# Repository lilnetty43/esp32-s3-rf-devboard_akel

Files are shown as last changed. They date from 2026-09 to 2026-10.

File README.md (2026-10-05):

# ESP32-S3 4-Layer RF Development Board

This project is a custom 4-layer development board built around the ESP32-S3. I designed the board to expand my PCB design experience into an RF-aware layout, multi-layer stackup design, controlled-impedance USB routing, and manufacturing preparation.

My board include native USB-C programming and power, 5 V-to-3.3 V regulation, GPIO breakout headers, BOOT and RESET controls, protection circuitry, test points, and a programmable RGB status LED.

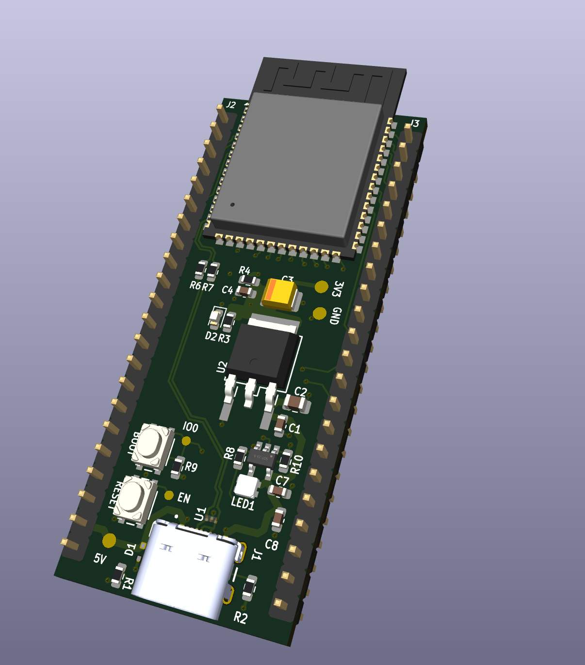
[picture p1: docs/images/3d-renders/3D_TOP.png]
3D Top View


*KiCad-generated 3D render of the ESP32-S3 development board.*

---

## Project Overview

The ESP32-S3 module provides Wi-Fi and Bluetooth connectivity using its integrated PCB antenna. The board exposes the ESP32-S3 GPIO through two headers while providing the supporting power, USB, programming, reset, and protection circuitry needed for standalone development.

A 4-layer PCB stackup was used to provide dedicated ground and power planes while maintaining short return paths and supporting controlled-impedance routing for the native USB interface.

---

## Details

- **MCU:** ESP32-S3 [LINK]
- **PCB:** 4-layer, 1.6 mm
- **USB:** USB-C with native ESP32-S3 USB programming[LINK]
- **USB Routing:** 90 Ω differential impedance target for D+/D−
- **Power Input:** 5V USB
- **Regulation:** 5V to 3.3V using LD1117S33 [LINK]
- **GPIO:** Dual breakout headers
- **Controls:** BOOT/RESET pushbuttons [LINK]
- **Protection:** USB ESD protection [LINK]
- **Status:** Programmable RGB LED [LINK]
- **Debugging:** Dedicated test points for important power and signal nets for debugging/checking

---

## PCB Stackup

The board uses a 4-layer stackup:
- **L1/F.Cu:** Components and signals
- **L2/In1.Cu:** Solid GND
- **L3/In2.Cu:** 3.3 V power 
- **L4/B.Cu:** Secondary signal routing

The stackup was configured around the intended JLCPCB manufacturing process rather than using KiCad's default layer construction.

---

## PCB Design Highlights [FIX!!!]

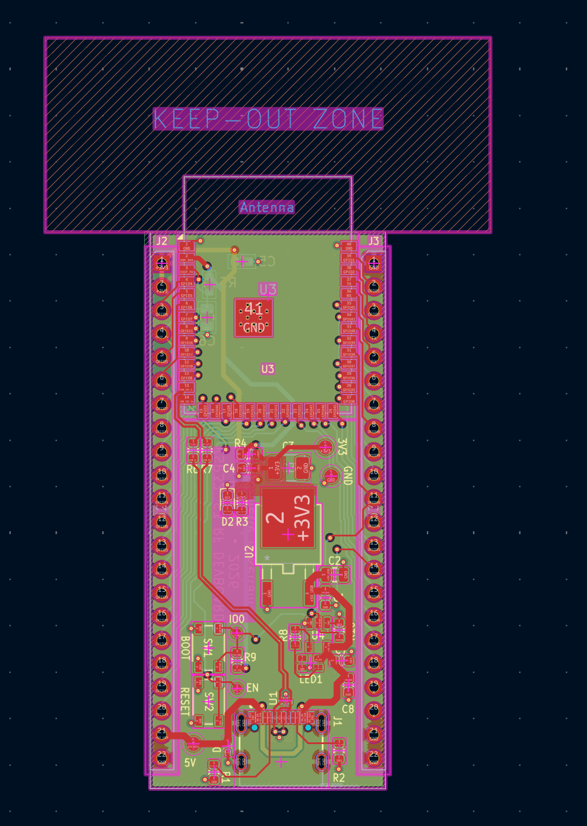
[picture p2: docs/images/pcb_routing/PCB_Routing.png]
PCB Routing


*Top PCB layout showing component placement and routed signals.*

---

## USB Differential Pair

The ESP32-S3 native USB interface was one of the primary high-speed layout considerations for this project.

The D+ and D− pair was routed using dimensions calculated for the selected 4-layer manufacturing stackup:

- **Target differential impedance:** 90 Ω
- **Reference plane:** L2 / In1.Cu GND
- **Routing layer:** L1 / F.Cu
- **Trace width:** 0.3051 mm
- **Pair spacing:** 0.1501 mm
- **Series termination:** 22 Ω

I utilized the JLCPCB resources and calculator to help determine this targeted impedance.

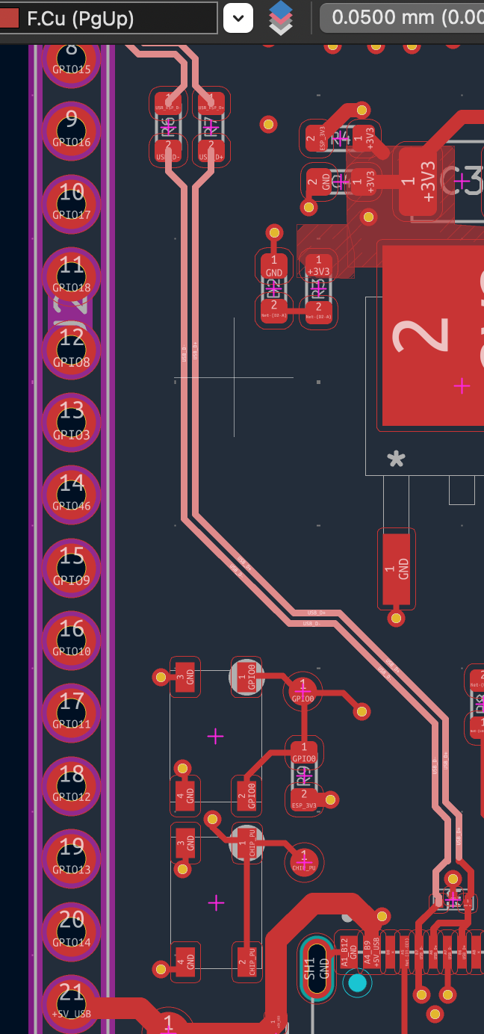
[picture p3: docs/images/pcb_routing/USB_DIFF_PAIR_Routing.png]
USB Differential Pair


*USB D+ and D− differential-pair routing between the USB-C interface and ESP32-S3.*

---

## Tools

- KiCad — schematic capture, PCB layout, routing, and 3D visualization
- JLCPCB impedance calculator (USB differential-pair geometry)
- Manufacturer datasheets and reference designs
- Git/GitHub
---

## Manufacturing

The PCB design and manufacturing files have been prepared for fabrication through JLCPCB.

Manufacturing/order status: **Pending**

---

## What I Learned

This was a fun project to dive into. i have expanded on my previous PCB work by introducing new design factors like:

- Working with an RF module and PCB antenna keepout requirements
- Revisiting USB differential-pair routing and controlled impedance
- Revisiting the design around dedicated internal ground and power planes
- Applying manufacturer-specific PCB constraints
- Preparing a complete PCB design for external fabrication

---

## Repo Structure

```text
esp32-s3-rf-devboard/
├── README.md
├── docs/
│   └── images/
│       ├── 3d_renders/
│       ├── pcb_routing/
│       └── schematic/
├── fabrication/
│   └── JLCPCB_REV1/
├── hardware/
│   ├── ESP32S3_RF_DevBoard.kicad_pro
│   ├── ESP32S3_RF_DevBoard.kicad_sch
│   └── ESP32S3_RF_DevBoard.kicad_pcb
└── manufacturing (PENDING)/

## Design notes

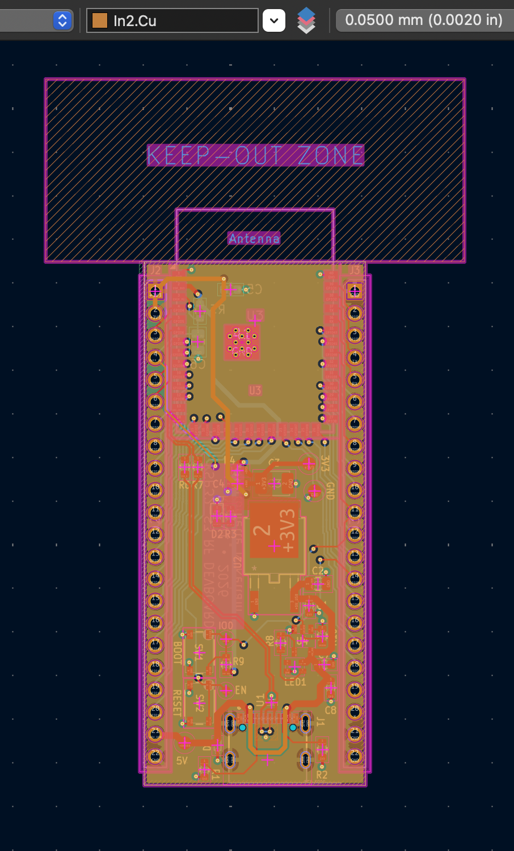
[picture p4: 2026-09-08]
docs/images/pcb_routing/In2.Cu.png

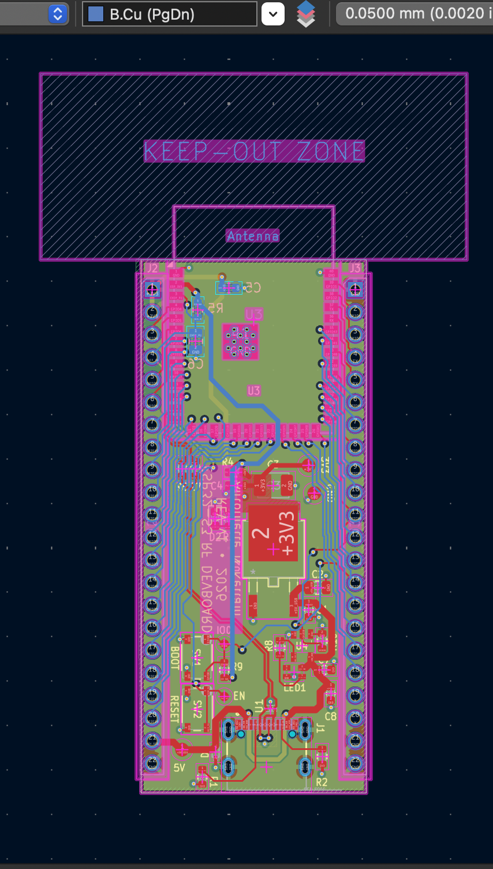
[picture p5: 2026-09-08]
docs/images/pcb_routing/B.Cu.png

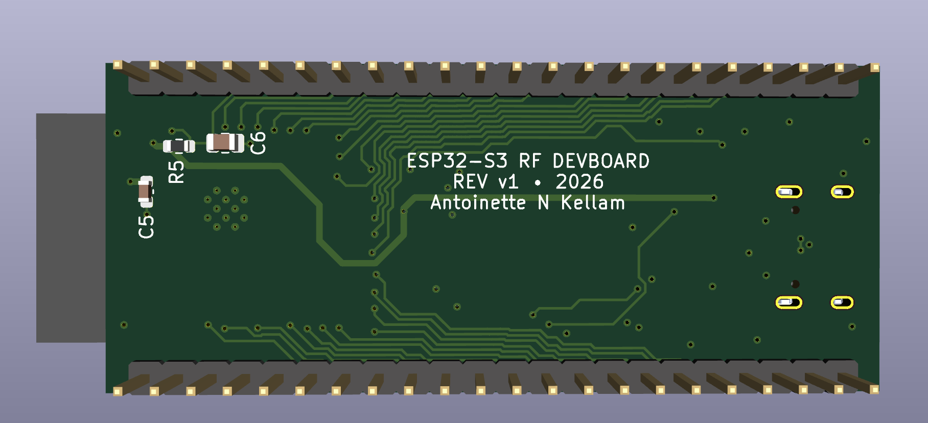
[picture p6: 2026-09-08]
docs/images/3d-renders/3D_BOT.png

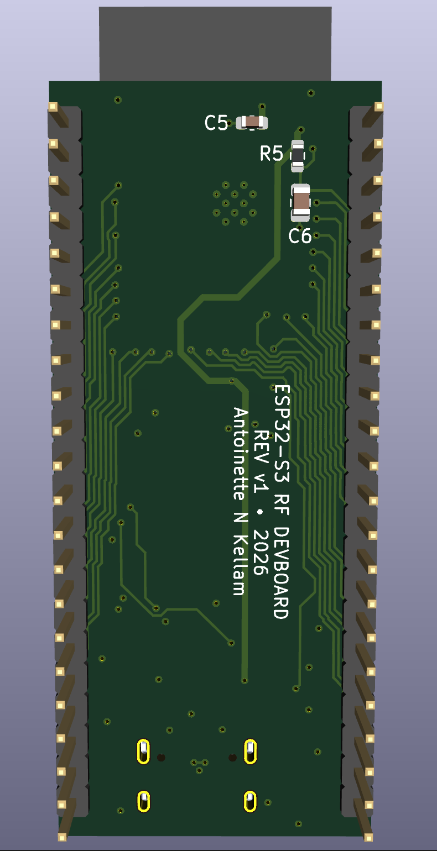
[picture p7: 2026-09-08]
docs/images/3d-renders/3D_BACK.png

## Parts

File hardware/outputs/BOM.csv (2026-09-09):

Reference | Component | Manufacturer | Manufacturer Part Number | LCSC Part Number | Quantity | Unit Price (USD) | Description | Notes | Link
C1, C5, C7, C8 | 0.1uF |  |  |  | 4 |  | 0603 ceramic capacitor | Decoupling capacitor
C2 | 4.7uF |  |  |  | 1 |  | 0805 capacitor
C3 | 10uF |  |  |  | 1 |  | EIA 3528-21 capacitor | Bulk capacitance
C4 | 10uF |  |  |  | 1 |  | 0603 ceramic capacitor | Bulk/decoupling capacitance
C6 | 1uF |  |  |  | 1 |  | 0805 ceramic capacitor
R1, R2, R3 | 5.1k |  |  |  | 3 |  | 0603 resistor
R5, R9, R10 | 10k |  |  |  | 3 |  | 0603 resistor
R6, R7 | 22R |  |  |  | 2 |  | 0603 resistor | USB D+/D- series resistors
R4 | 0R |  |  |  | 1 |  | 0603 resistor | 0-ohm resistor
R8 | 33R |  |  |  | 1 |  | 0603 resistor
D1 | LESD5D5.0CT1G |  |  |  | 1 |  | TVS protection diode
D2 | RED |  |  |  | 1 |  | 0603 red LED | Status LED
U1 | ESD122DMYR |  |  |  | 1 |  | USB ESD protection device | USB D+/D- protection
U2 | LD1117DT33CTR | STMicroelectronics | LD1117DT33CTR |  | 1 |  | 3.3 V linear regulator | 5 V to 3.3 V regulation
U3 | ESP32-S3-WROOM-1-N8 | Espressif | ESP32-S3-WROOM-1-N8 |  | 1 |  | ESP32-S3 Wi-Fi/Bluetooth module | Main MCU and RF module
U4 | SN74AHCT1G125DBVR |  |  |  | 1 |  | Single buffer/level interface
SW1 | BOOT |  |  |  | 1 |  | Momentary pushbutton | BOOT control
SW2 | RESET |  |  |  | 1 |  | Momentary pushbutton | RESET control
LED1 | XL-2121RGBC-WS2812B |  |  |  | 1 |  | Addressable RGB LED | Programmable status LED
J2, J3 | Conn_01x22 |  |  |  | 2 |  | 1x22 2.54 mm vertical headers | GPIO breakout headers
J1 | USB4105-GF-A | GCT | USB4105-GF-A | C3020560 | 1 |  | USB Type-C receptacle | USB power and native USB interface

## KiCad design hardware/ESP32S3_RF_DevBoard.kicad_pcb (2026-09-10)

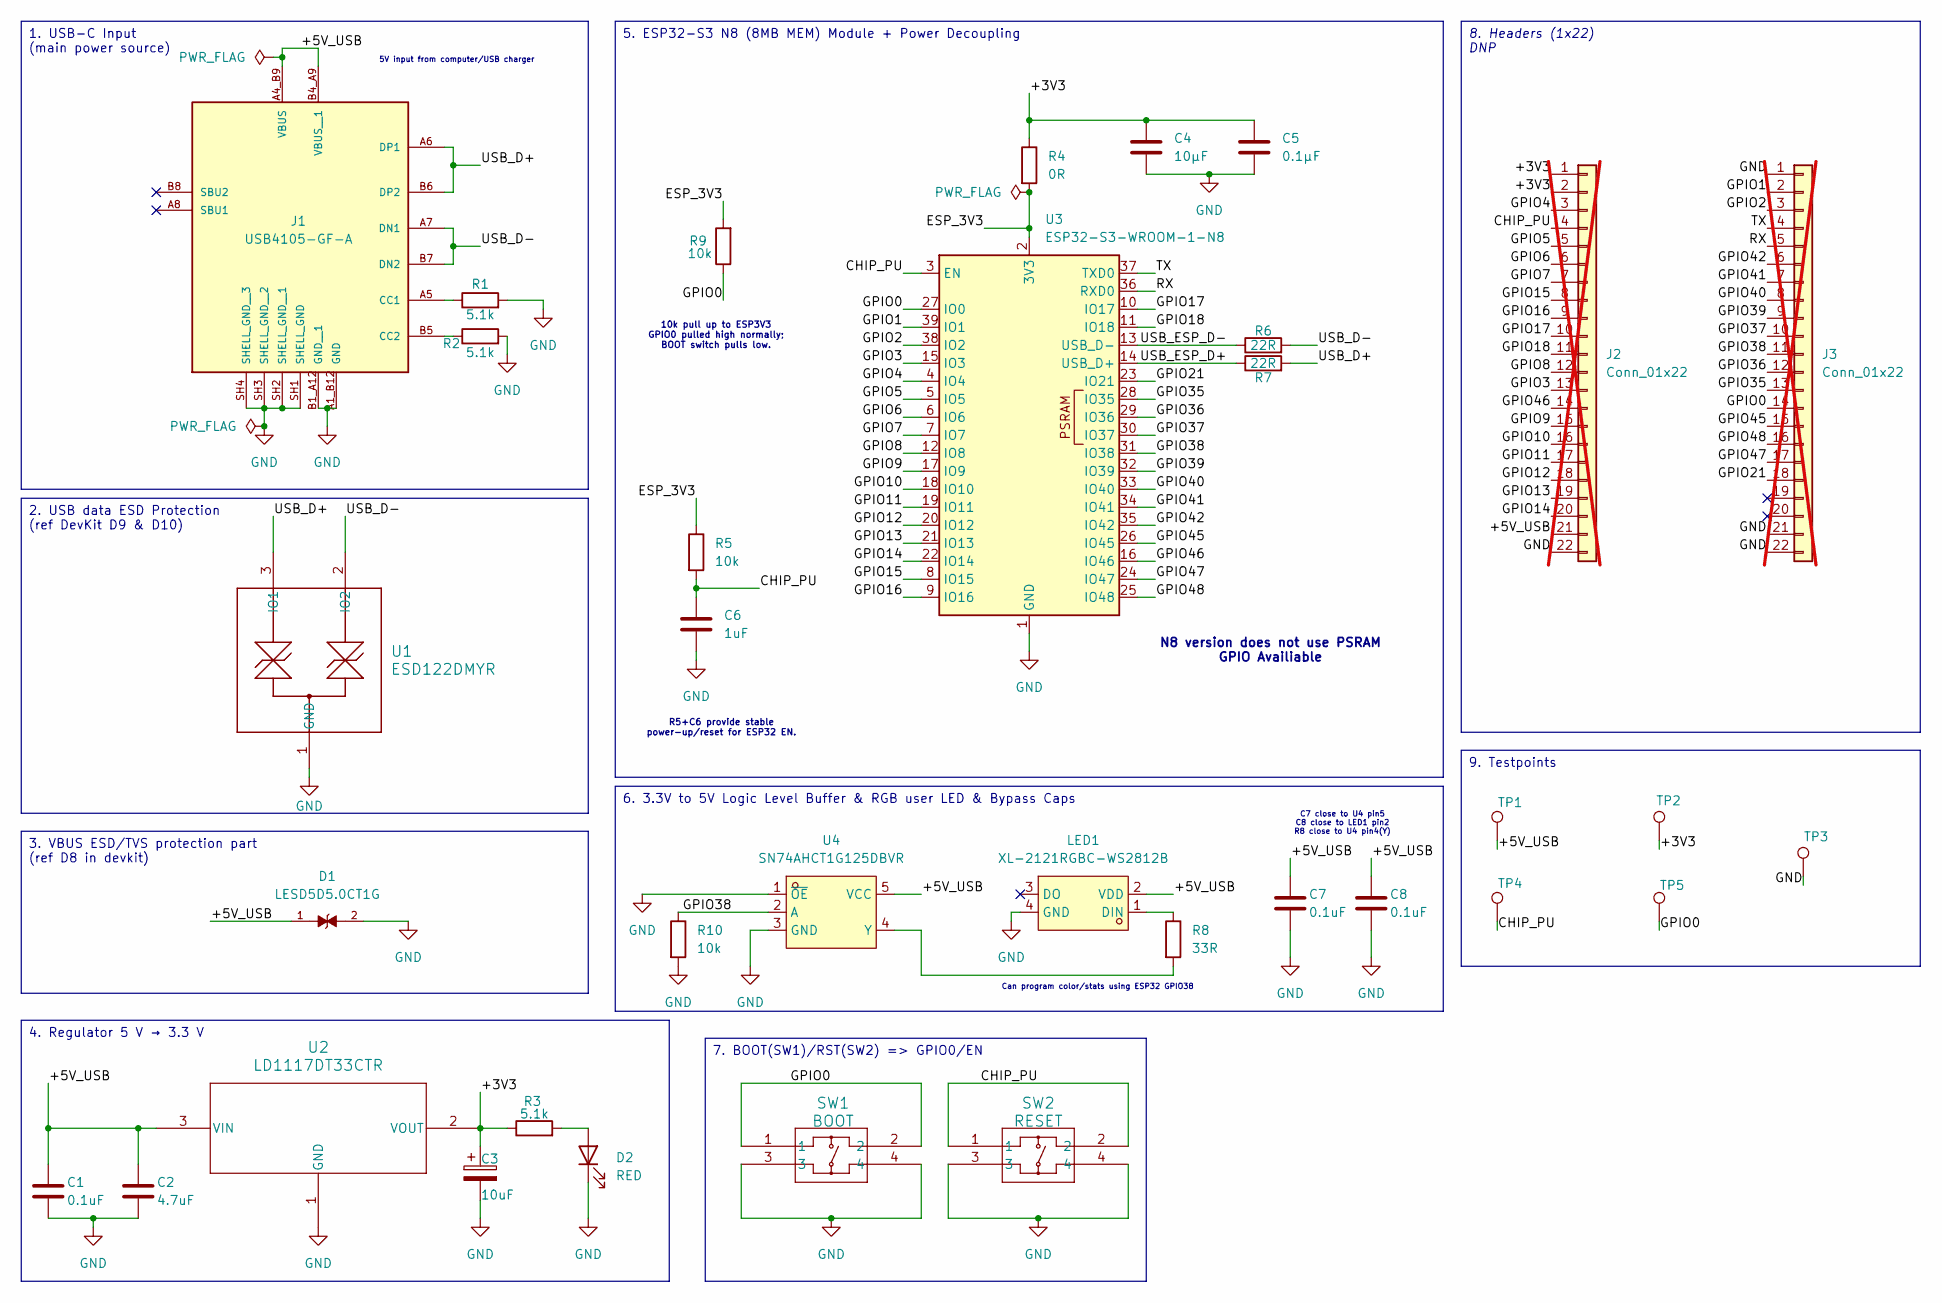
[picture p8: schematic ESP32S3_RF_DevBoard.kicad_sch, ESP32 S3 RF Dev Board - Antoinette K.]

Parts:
C1, C7, C8: 0.1uF; C_0603_1608Metric; MPN 0603B104K160CT; LCSC C80516
C2: 4.7uF; C_0805_2012Metric; MPN FS21B475K160EIG; LCSC C2929196
C3: 10uF; CP_EIA-3528-21_Kemet-B; MPN T491B106M016AT; LCSC/JLCPCB C118754
C4: 10µF; C_0603_1608Metric; Voltage 25V; Tolerance ±20%; MPN GRM188R61E106MA73D; LCSC/JLCPCB C91606
C5: 0.1µF; C_0603_1608Metric; Voltage 50V; Tolerance ±10%; MPN CL10B104KB8NNNC; LCSC/JLCPCB C1591
C6: 1uF; C_0805_2012Metric; Voltage 16V; Tolerance ±10%; MPN CL21B105KOFNNNE; LCSC/JLCPCB C24123
D1: LESD5D5.0CT1G; TVS_LESD5D5.0CT1G; PARTREV O
D2: RED; LED_0603_1608Metric; MPN KT-0603R; LCSC/JCLPCB C2286
J1: USB4105-GF-A; GCT_USB4105-GF-A; PARTREV B4
J2, J3: Conn_01x22; PinHeader_1x22_P2.54mm_Vertical; MPN PZ254V-11-22P; JLCPCB/LCSC C22465881; not fitted
LED1: XL-2121RGBC-WS2812B; LED-SMD_4P-L2.1-W2.1-BR_XL-2121RGBC-WS2812B; MPN XL-2121RGBC-2812B; LCSC Part C5349957
R1, R2: 5.1k; R_0603_1608Metric; JLCPCB/LCSC C14677
R3: 5.1k; R_0603_1608Metric; Tolerance ±5%
R4: 0R; R_0603_1608Metric; LCSC/JLCPCB C21189
R5, R9, R10: 10k; R_0603_1608Metric; MPN 0603WAF1002T5E; LCSC/JLCPCB C25804
R6, R7: 22R; R_0603_1608Metric; Tolerance ±1%; MPN 0603WAF220JT5E; LCSC/JLCPCB C23345
R8: 33R; R_0603_1608Metric; MPN 0603WAF330JT5E; LCSC/JLCPCB C23140
SW1: BOOT; SKRPANE010_AAL; MPN SKRPANE010; JLCPCB/LCSC C470426
SW2: RESET; SKRPANE010_AAL; MPN SKRPANE010; JLCPCB/LCSC C470426
TP1, TP2, TP3: TestPoint; TestPoint_Pad_D1.5mm
TP4, TP5: TestPoint; TestPoint_Pad_D1.0mm
U1: ESD122DMYR; DMY0003A
U2: LD1117DT33CTR; DPAK_STM
U3: ESP32-S3-WROOM-1-N8; ESP32-S3-WROOM-1
U4: SN74AHCT1G125DBVR; SOT-23-5_L3.0-W1.7-P0.95-LS2.8-BR; MPN SN74AHCT1G125DBVR; LCSC Part C7484

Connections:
/+3V3: C3.1, C4.1, C5.1, J2.1, J2.2, R3.1, R4.1, TP2.1 (1_1), U2.2 (VOUT)
/+5V_USB: C1.1, C2.1, C7.1, C8.1, D1.1, J1.A4_B9 (VBUS), J1.B4_A9 (VBUS__1), J2.21, LED1.2 (VDD), TP1.1 (1_1), U2.3 (VIN), U4.5 (VCC)
/CHIP_PU: C6.1, J2.4, R5.2, SW2.1, SW2.2, TP4.1 (1_1), U3.3 (EN)
/ESP_3V3: R4.2, R5.1, R9.2, U3.2 (3V3)
/GPIO0: J3.14, R9.1, SW1.1, SW1.2, TP5.1 (1_1), U3.27 (IO0)
/GPIO1: J3.2, U3.39 (IO1)
/GPIO2: J3.3, U3.38 (IO2)
/GPIO3: J2.13, U3.15 (IO3)
/GPIO4: J2.3, U3.4 (IO4)
/GPIO5: J2.5, U3.5 (IO5)
/GPIO6: J2.6, U3.6 (IO6)
/GPIO7: J2.7, U3.7 (IO7)
/GPIO8: J2.12, U3.12 (IO8)
/GPIO9: J2.15, U3.17 (IO9)
/GPIO10: J2.16, U3.18 (IO10)
/GPIO11: J2.17, U3.19 (IO11)
/GPIO12: J2.18, U3.20 (IO12)
/GPIO13: J2.19, U3.21 (IO13)
/GPIO14: J2.20, U3.22 (IO14)
/GPIO15: J2.8, U3.8 (IO15)
/GPIO16: J2.9, U3.9 (IO16)
/GPIO17: J2.10, U3.10 (IO17)
/GPIO18: J2.11, U3.11 (IO18)
/GPIO21: J3.18, U3.23 (IO21)
/GPIO35: J3.13, U3.28 (IO35)
/GPIO36: J3.12, U3.29 (IO36)
/GPIO37: J3.10, U3.30 (IO37)
/GPIO38: J3.11, R10.1, U3.31 (IO38), U4.2 (A)
/GPIO39: J3.9, U3.32 (IO39)
/GPIO40: J3.8, U3.33 (IO40)
/GPIO41: J3.7, U3.34 (IO41)
/GPIO42: J3.6, U3.35 (IO42)
/GPIO45: J3.15, U3.26 (IO45)
/GPIO46: J2.14, U3.16 (IO46)
/GPIO47: J3.17, U3.24 (IO47)
/GPIO48: J3.16, U3.25 (IO48)
/RX: J3.5, U3.36 (RXD0)
/TX: J3.4, U3.37 (TXD0)
/USB_D+: J1.A6 (DP1), J1.B6 (DP2), R7.2, U1.3 (IO1)
/USB_D-: J1.A7 (DN1), J1.B7 (DN2), R6.2, U1.2 (IO2)
/USB_ESP_D+: R7.1, U3.14 (USB_D+)
/USB_ESP_D-: R6.1, U3.13 (USB_D-)
GND: C1.2, C2.2, C3.2, C4.2, C5.2, C6.2, C7.2, C8.2, D1.2, D2.1 (K), J1.A1_B12 (GND), J1.B1_A12 (GND__1), J1.SH1 (SHELL_GND), J1.SH2 (SHELL_GND__1), J1.SH3 (SHELL_GND__2), J1.SH4 (SHELL_GND__3), J2.22, J3.1, J3.21, J3.22, LED1.4 (GND), R1.2, R2.2, R10.2, SW1.3, SW1.4, SW2.3, SW2.4, TP3.1 (1_1), U1.1 (GND), U2.1 (GND), U3.1 (GND), U3.40 (GND), U3.41 (GND), U4.1 (~OE), U4.3 (GND)
unnamed: D2.2 (A), R3.2
unnamed: J1.A5 (CC1), R1.1
unnamed: J1.B5 (CC2), R2.1
unnamed: LED1.1 (DIN), R8.1
unnamed: R8.2, U4.4 (Y)

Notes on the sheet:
C7 close to U4 pin5 C8 close to LED1 pin2 R8 close to U4 pin4(Y)
10k pull up to ESP3V3 GPIO0 pulled high normally; BOOT switch pulls low.
N8 version does not use PSRAM GPIO Availiable
5V input from computer/USB charger
R5+C6 provide stable power-up/reset for ESP32 EN.
Can program color/stats using ESP32 GPIO38
3. VBUS ESD/TVS protection part (ref D8 in devkit)
8. Headers (1x22) DNP
4. Regulator 5 V → 3.3 V
7. BOOT(SW1)/RST(SW2) => GPIO0/EN
1. USB-C Input (main power source)
6. 3.3V to 5V Logic Level Buffer & RGB user LED & Bypass Caps
9. Testpoints
5. ESP32-S3 N8 (8MB MEM) Module + Power Decoupling
2. USB data ESD Protection (ref DevKit D9 & D10)

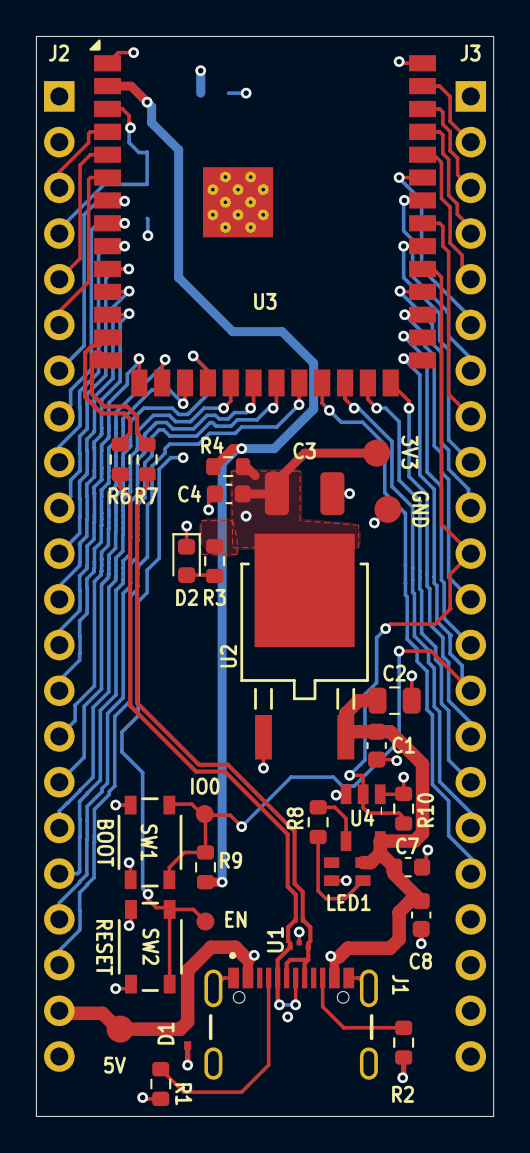
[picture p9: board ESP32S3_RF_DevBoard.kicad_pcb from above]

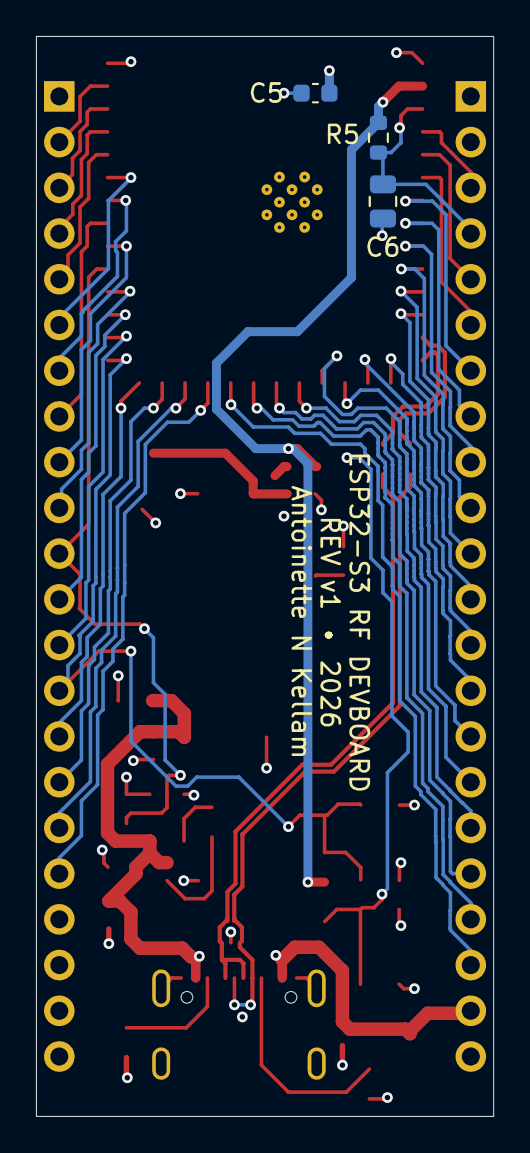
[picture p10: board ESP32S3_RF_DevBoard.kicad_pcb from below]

Board: 4 copper layers, 25.4 x 60.0 mm, 35 parts (3 on the bottom side), 48 nets.

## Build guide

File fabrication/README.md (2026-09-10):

This directory contains Drill and Gerber source files for the project.

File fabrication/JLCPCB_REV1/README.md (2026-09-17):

This directory contains the complete hardware design drill/gerber files zip
---

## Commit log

2026-08-04 intial commit project creation in kicad
    [ESP32S3_RF_DevBoard.kicad_pcb, ESP32S3_RF_DevBoard.kicad_sch]
2026-08-04 organizing project structure
    [ESP32S3_RF_DevBoard.kicad_pcb, ESP32S3_RF_DevBoard.kicad_sch]
2026-08-11 working on first block- usb-c block
    [ESP32S3_RF_DevBoard.kicad_sch]
2026-08-12 working on the USB data ESD blk
    [ESP32S3_RF_DevBoard.kicad_sch]
2026-08-12 editing for next block - vbus protection
    [ESP32S3_RF_DevBoard.kicad_sch]
2026-08-14 continuing to add major block - 5 to 3.3V regulator next. - need to get symbol, footprints, into library now
    [ESP32S3_RF_DevBoard.kicad_sch]
2026-08-17 working on 5v to 3v3 regulator - reviewing and checking
    [ESP32S3_RF_DevBoard.kicad_sch]
2026-08-18 Fixing ERC on the ldo block
    [ESP32S3_RF_DevBoard.kicad_sch]
2026-08-18 adding in the ESP module and switches - need to now go through and add R's on USB traces from the Espresif guide recs
    [ESP32S3_RF_DevBoard.kicad_sch]
2026-08-19 now working on the 1x22 headers
    [ESP32S3_RF_DevBoard.kicad_sch]
2026-08-19 working on adding a level buffer 3.3v to 5v for the RGB
    [ESP32S3_RF_DevBoard.kicad_sch]
2026-08-19 editing for next block level buffer
    [ESP32S3_RF_DevBoard.kicad_sch]
2026-08-20 finalizing the schematic and double checking connections and proper decoupling CAP
    [ESP32S3_RF_DevBoard.kicad_sch]
2026-08-20 going through schematic for connections and running ERC - as of now ERC is clean
    [ESP32S3_RF_DevBoard.kicad_sch]
2026-08-25 editing board stackup
    [ESP32S3_RF_DevBoard.kicad_pcb]
2026-08-25 - did board setup and constraints - did net classes - confirmed board outline and dimesions - placing U3 with the keepout area in mind heree
    [ESP32S3_RF_DevBoard.kicad_pcb]
2026-08-26 placement of all components and editing skilscreen rules
    [ESP32S3_RF_DevBoard.kicad_pcb, ESP32S3_RF_DevBoard.kicad_sch]
2026-08-26 - made In.Cu GND plane - next: working on the routing USB.
    [ESP32S3_RF_DevBoard.kicad_pcb]
2026-08-28 -edits to vias placements
    [ESP32S3_RF_DevBoard.kicad_pcb]
2026-08-30 - working on the diff pairs (D-/D+) of USB.
    [ESP32S3_RF_DevBoard.kicad_pcb]
2026-08-31 working on routing still - completed USB routing diff pair
    [ESP32S3_RF_DevBoard.kicad_pcb]
2026-09-02 - 5 unconnected components as of now! - trying to route the rest of the GPIO and CHIP_PU traces - will deal with silkscreen and footprint warnings last !
    [ESP32S3_RF_DevBoard.kicad_pcb, ESP32S3_RF_DevBoard.kicad_sch]
2026-09-02 working on silkscreen warnings and fixing . - all routing complete (0 unconnections) - verfiy in JLCPCB USB NPTH hole placeement (may have to exclude the error if JLCPCB clears through dfm)
    [ESP32S3_RF_DevBoard.kicad_pcb, ESP32S3_RF_DevBoard.kicad_sch]
2026-09-03 routing done. - need to verify JLCPCB for the NPTH to track clearance.
    [ESP32S3_RF_DevBoard.kicad_pcb]
2026-09-03 edit - will export gerbers / drills for now to check on the NPTH
2026-09-03 - as of now i will recalculate the impedance of the board for the USB diff pairs for the JLCPCB no stackup control requiekment. - will have to change the width and gap of the USB_DIFF on the board - 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
    [ESP32S3_RF_DevBoard-B_Cu.gbl, ESP32S3_RF_DevBoard-B_Mask.gbs, ESP32S3_RF_DevBoard-B_Paste.gbp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]
2026-09-08 - checking the drc - checking manufacturing for the USB receptacle - checking diff routing (diff imp check) rerouted - adding imgs a - adding in gerbers and drill files
    [ESP32S3_RF_DevBoard-B_Cu.gbl, ESP32S3_RF_DevBoard-B_Mask.gbs, ESP32S3_RF_DevBoard-B_Paste.gbp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]
2026-09-09 - creating BOM - gathering docs and compoennts for BOM (finalizing)
    [BOM.csv]
2026-09-09 - edting BOM with parts
    [BOM.csv]
2026-09-09 - BOM edit
    [BOM.csv]
2026-09-10 - edits
    [ESP32S3_RF_DevBoard.kicad_pcb]
2026-09-10 - editing drill/gerbers
    [ESP32S3_RF_DevBoard-B_Cu.gbl, ESP32S3_RF_DevBoard-B_Mask.gbs, ESP32S3_RF_DevBoard-B_Paste.gbp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]
2026-09-10 - new drill/gerbers
    [ESP32S3_RF_DevBoard-B_Cu.gbl, ESP32S3_RF_DevBoard-B_Mask.gbs, ESP32S3_RF_DevBoard-B_Paste.gbp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]
2026-09-10 - moving drill / geber files
    [ESP32S3_RF_DevBoard-NPTH-drl_map.gbr, ESP32S3_RF_DevBoard-NPTH.drl, ESP32S3_RF_DevBoard-PTH-drl_map.gbr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]
2026-09-10 - gerber moove
    [ESP32S3_RF_DevBoard-B_Cu.gbl, ESP32S3_RF_DevBoard-B_Mask.gbs, ESP32S3_RF_DevBoard-B_Paste.gbp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]
